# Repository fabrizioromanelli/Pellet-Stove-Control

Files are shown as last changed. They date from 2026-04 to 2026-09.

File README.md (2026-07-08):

# Pellet Stove Control  

<a href="https://buymeacoffee.com/fabrizioroz" target="_blank">
  Buy Me A Coffee
</a>

**I have prebuilt kits, ask me if you need any information!**

This project allows you to smart control any pellet stove controlled via a Micronova Controller N100.
The Arduino project has been compiled for an ESP8266 and successfully tested on a Micronova N100 Controller.
Any other board from Micronova could work, but this is left to the user/developer (probably something changes
on the memory mapping side).
The program is written for Arduino, and it is tested on a D1 Mini with full integration for MQTT (Home Assistant, OpenHAB).

## The Pellet Stove Control works with
the following pellet stoves (please ask me before to check if this could work with your
pellet stove!).
<details>
<summary><b>Compatible pellet stoves</b></summary>

- AMG S.p.A. (Artel, Kalor, Tepor, Foco, Adler)
- Anselmo Cola
- L'Asolana
- Boreal
- Bronpi
- Cadel
- Clam
- Corisit S.r.l. (Lincar, Vulcania, Arce)
- Ecoteck
- EL.FIRE
- EOSS
- EvaCalor
- Fontana Calore
- Fonte Flamme
- Galletti
- Globe-Fire
- Italiana Camini
- Jolly Mec
- Karmek
- Kepo
- Klover
- Laminox
- LMX
- La Nordica S.p.A (Extraflame, Dal Zotto)
- Lorflam
- MCZ (Brisach, Cadel, FreePoint, Pegaso, Red)
- Moretti Design
- Nordic Fire
- Piazetta
- Sicalor
- Solius
- Stufe a pellet Italia
- Tecnoflam
- Termoflam
- Thermoflux
- TS
- Ungaro
- Zibro
- Kalor Compact (boiler, fumesTempAddr 0xFF, flamePowerAddr 0x37)
- ITC Layma (boiler, fumesTempAddr 0x5A, no water pressure value available)
- ETNA Giulia EVO (Micronova J042, fumes temp and power reading doesn't work for the moment)
- Extraflame Teodora Evo (at least turning on works)
- El.Fire Venice Slim
- Palazzetti Ecofire Violetta 7 (tested)
- RED Loto
- MCZ Kaika/Face
- FreePoint Sharp
- Piazetta P958D
- Piazetta Line
- Anselmo Cola Aloe
- Solius Geres
- L'Asolana Marina
</details>

## Components
The following components are needed:
- An ESP8266 (D1 Mini or similar).
- 3 x PC817.
- 3 x 510 Ohms resistors.
- 1 x RJ11 male connector (if your stove has a female RJ11 connected to the serial interface).
- 1 x DB9 (DE-9) male connector (if your stove has an DB9 female connector).

## Circuit diagram
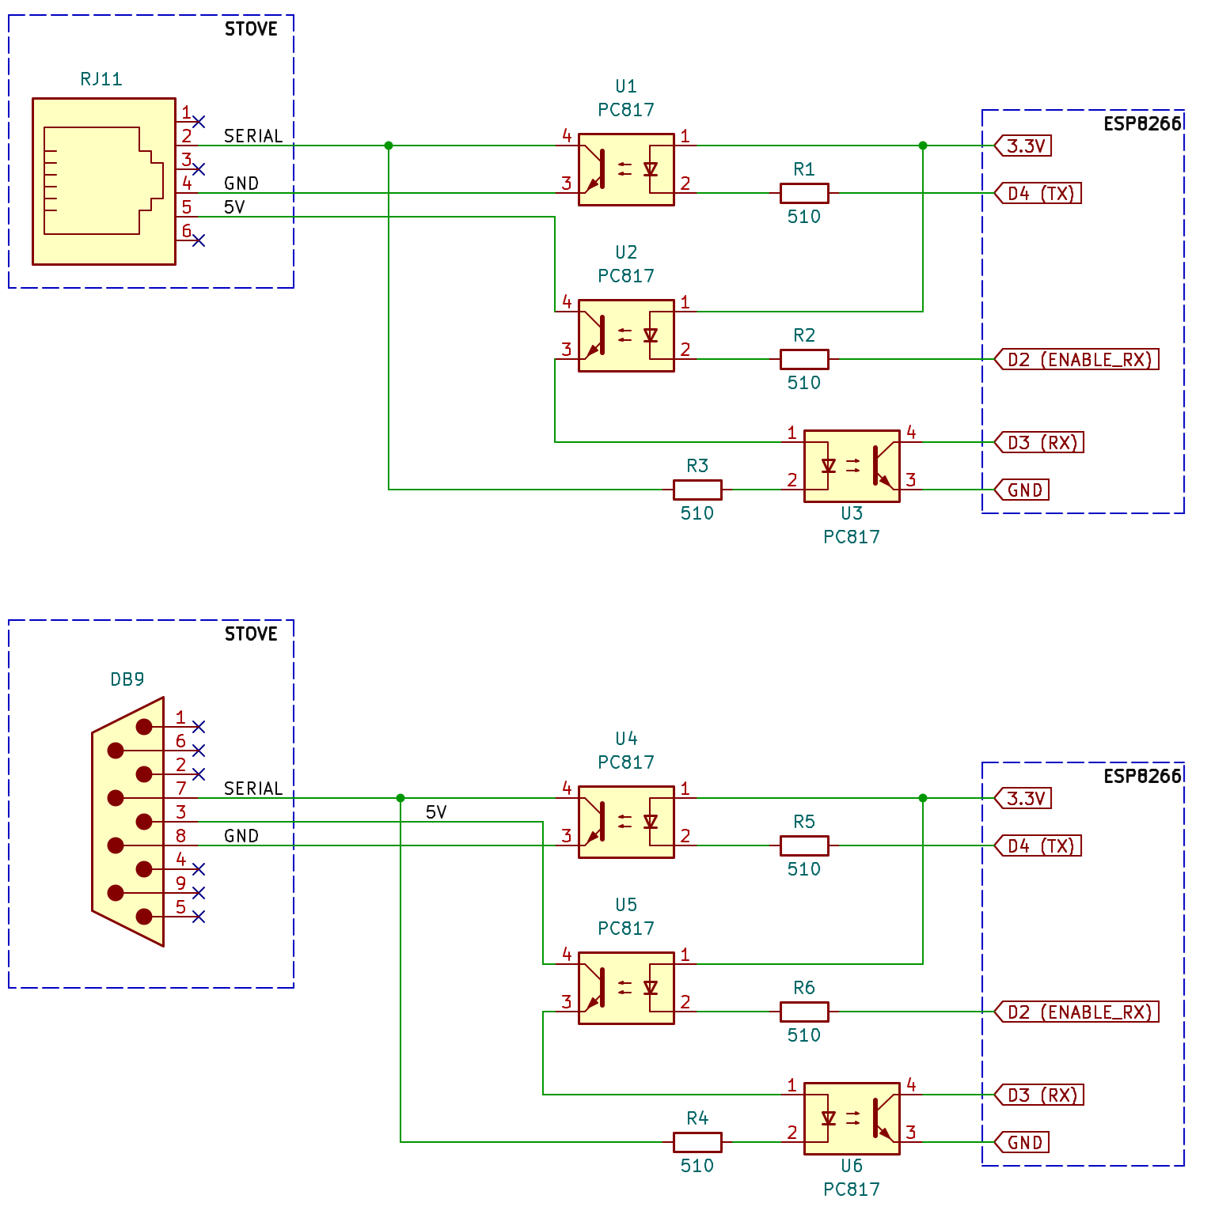
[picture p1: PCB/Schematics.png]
Schematics


For ESP8266 the IN/OUT matrix is:

|ESP8266 I/O|Function|
|---|---|
|`D2`|`Enable RX`|
|`D3`|`RX`|
|`D4`|`TX`|

For ESP32 the IN/OUT matrix is:

|ESP32 I/O|Function|
|---|---|
|`GPIO35`|`Enable RX`|
|`GPIO32`|`RX`|
|`GPIO33`|`TX`|

## Micronova N100 serial port pinout

Serial pinout for both DE-9 and RJ11 connectors

The scheme shows the serial pinout from the Micronova N100 serial port with the connections for both the DE-9 connector and the RJ11 connector.

|Color|Function|
|---|---|
|`Blue`|`Serial`|
|`Red`|`+5V`|
|`Black`|`Ground`|

The fourth pin (the leftmost on the N100 board) is not used.

## PCB project
The folder PCB contains the project for the Printed Circuit Board of the Pellet Stove Control.

Front PCB board:

PCB Front

Back PCB board:

PCB Retro

## Micronova board pinout
For the details related to the board pinout, refer to the manual. This project allows you to interface the stove with the serial port of the Micronova controller. Ask me in case of any doubts.

## Protocol for Micronova controller interface
The protocol for the Micronova controller has been reverse engineered and it is as stable as possible; there is a known problem with writing some values for controlling the stove (such as Flame Power and Fan Speed) that are mapped on the EEPROM (rather than on RAM), however this has been included in the project to let the user control all the stove parameters.

## Building the project
No MQTT parameter needs to be hardcoded in the sketch: everything is configured at first boot through the WiFiManager captive portal and then persisted on the board itself.

- Build the sketch with the Arduino IDE (no editing required)
- Upload the sketch on the board
- On first boot (or whenever the WiFi settings are reset), connect to the `PelletStove-Setup` WiFi network from your phone/PC
- The browser should redirect to the configuration page where you can set up your WiFi credentials, together with the following MQTT parameters:
  - **MQTT server**, the IP or hostname of your MQTT broker
  - **MQTT port**, usually `1883`
  - **MQTT base topic**, the name of the topic you choose to publish on
  - **MQTT user**, if any
  - **MQTT password**, if any
- Once submitted, the board connects to your WiFi/MQTT broker and stores all these settings on the board's flash (LittleFS), so they are restored automatically on every subsequent reboot
- To change the settings later on, reset the WiFi credentials (e.g. via the WiFiManager reset routine) so the `PelletStove-Setup` portal comes up again, pre-filled with the previously saved values

## MQTT topics
- `mqtt_topic`, this is the main topic.
- `connection_state`, this topic contains connection details.
- `state`, this topic contains the detailed status of the stove.
- `power_state`, this topic contains information about the stove power on/off.
- `ta_state`, this topic contains the ambient temperature.
- `ts_state` this topic is used to read the target temperature.
- `tf_state`, this topic is used to read the fumes temperature.
- `p_state`, this topic is used to read the flame power (%).
- `f_state`, this topic is used to read the fan speed (1-5).
- `cmd`, is the topic used to control the stove.

### Command currently supported by the Pellet Stove Control
|Command |Description | Write to |
|---|---|---|
|`ON` |powers on the pellet stove  | RAM |
|`OFF` | shutdown the pellet stove  | RAM |
|`Px`  |sets the power of the pellet stove. e.g. P2 sets the power @ 2 [0 to 5]  | EEPROM |
|`Fx`  |sets the fan speed of the pellet stove. e.g. F0 sets the fan speed to automatic [0 to 5] | EEPROM |
|`Txx`  |sets the target temperature of the pellet stove. e.g. T20 sets the target temperature to 20 °C [10-40]  | EEPROM |
|`E`  |resets any error on the stove | RAM |

Since there is no other way to set flame power/fan speed/temperature rather than writing on the EEPROM, please pay attention to the final integration as EEPROM writes are limited (~10000).

## Home Assistant
For Home Assistant support, please contact me.

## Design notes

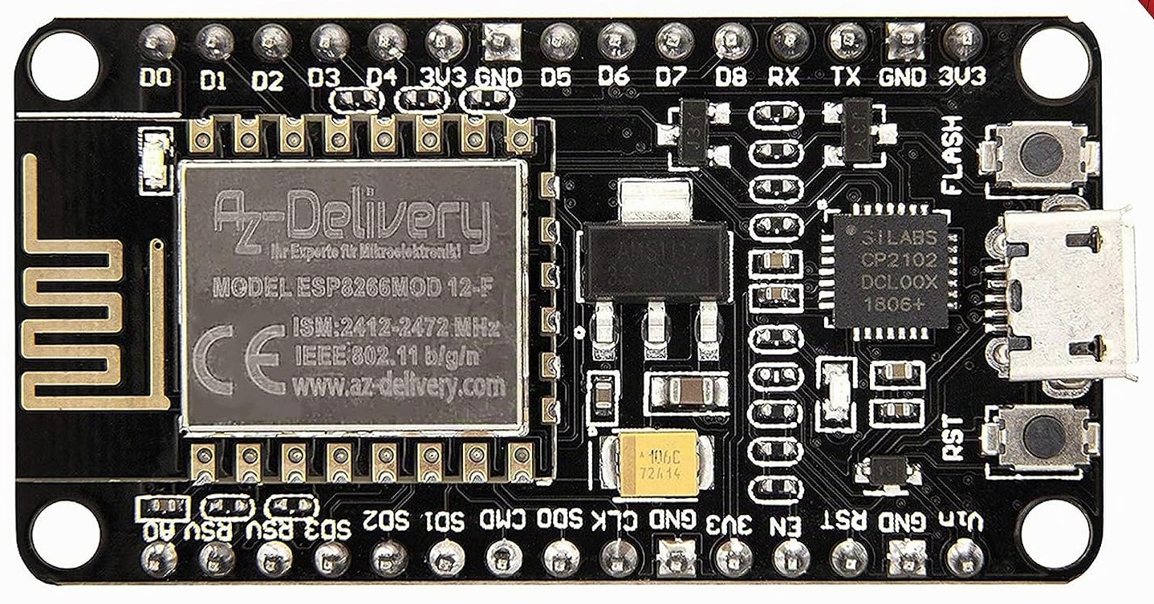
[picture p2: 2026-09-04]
PCB/AZDelivery NodeMCU Amica V2 ESP8266 ESP-12F, Modulo Wifi IoT con CP2102.jpg

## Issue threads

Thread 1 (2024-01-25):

Details for PCB

wes1993, 2024-01-25:
Hello,
thanks a lot for PCB projects, could you give me some information why there are different files?

Best regards
Stefano

fabrizioromanelli, 2024-01-25:
> Hello, thanks a lot for PCB projects, could you give me some information why there are different files?
>
> Best regards Stefano

Sure!
The backup folder inside the PCB folder is just a backup from previous work, you can just ignore it.
All the other files (.kicad*) are used by the KiCAD software to store all the details related to the PCB layers.
Hope this could help! Also, I have some spare PCBs. If you need any, send me an email.

Closed 2024-01-26.

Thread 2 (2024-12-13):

Esphome

goldrake1981, 2024-12-13:
C'è un modo per collegarla a esphome ?
Grazie

fabrizioromanelli, 2024-12-13:
Se esphome supporta MQTT, allora il collegamento è semplice e si può fare.

goldrake1981, 2024-12-13:
Cercavo un modo comodo per installarla su home assistant, soprattutto qualcosa che potesse permettermi di aggiornare il codice con semplicità . Solo che non sono in grado.  Pensavo ci fosse qualche esempio .

fabrizioromanelli, 2024-12-16:
Capisco, prima bisognerebbe installare la parte del firmware su ESP e poi interfacciare la scheda con Home Assistant

goldrake1981, 2024-12-16:
Devo studiare.  Ne so veramente poco e niente.

Closed 2024-12-13.

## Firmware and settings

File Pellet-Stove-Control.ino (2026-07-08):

#include <ArduinoOTA.h>
#include <WiFiManager.h>
#include <PubSubClient.h>
#include <SoftwareSerial.h>
#include <LittleFS.h>

#define AP_NAME "PelletStove-Setup"    // Access point name shown on first boot / config reset
#define CONFIG_FILE "/mqtt_config.txt" // Where MQTT settings are persisted on LittleFS

char mqtt_server[41] = "";
char mqtt_port[7]    = "1883";
char mqtt_topic[41]  = "";
char mqtt_user[21]   = "";
char mqtt_pass[21]   = "";

bool shouldSaveConfig = false; // Set by WiFiManager when the config portal is submitted

unsigned long UPDATE_PERIOD = 1800000; // 30m (in ms)
unsigned long FAST_UPDATE_PERIOD = 60000; // 1m (in ms)

#define FAST_LOOP_CYCLES 30

SoftwareSerial StoveSerial;
#define SERIAL_MODE SWSERIAL_8N2
#define RX_PIN D3
#define TX_PIN D4
#define ENABLE_RX D2

WiFiClient espClient;
PubSubClient client(espClient);
WiFiManager wm;

static volatile bool sem = false;
bool fastUpdate = false;
bool boot = true;
static unsigned long loopCounter = 0;
unsigned long previousMillis = 0;

char connection_topic[52];
char state_topic[52];
char onoff_topic[52];
char ambtemp_topic[52];
char fumetemp_topic[52];
char flame_topic[52];
char fan_topic[52];
char tempset_topic[52];
char cmd_topic[52];

// mqtt_topic is only known at runtime now, so the full topics are built here instead of via macros
void buildTopics() {
  snprintf(connection_topic, sizeof(connection_topic), "%s/connection", mqtt_topic);
  snprintf(state_topic,      sizeof(state_topic),      "%s/state",      mqtt_topic);
  snprintf(onoff_topic,      sizeof(onoff_topic),      "%s/onoff",      mqtt_topic);
  snprintf(ambtemp_topic,    sizeof(ambtemp_topic),    "%s/ambtemp",    mqtt_topic);
  snprintf(fumetemp_topic,   sizeof(fumetemp_topic),   "%s/fumetemp",   mqtt_topic);
  snprintf(flame_topic,      sizeof(flame_topic),      "%s/power",      mqtt_topic);
  snprintf(fan_topic,        sizeof(fan_topic),        "%s/fan",        mqtt_topic);
  snprintf(tempset_topic,    sizeof(tempset_topic),    "%s/tempset",    mqtt_topic);
  snprintf(cmd_topic,        sizeof(cmd_topic),        "%s/cmd",        mqtt_topic);
}

#define device_information "{\"manufacturer\": \"Fabrizio Romanelli\",\"identifiers\": [\"7a396f39-80d2-493b-8e8e-31a70e700bc6\"],\"model\": \"Micronova Controller\",\"name\": \"Micronova Controller\",\"sw_version\": \"1.0.0.0\"}"

#define _RAMR 0x00
#define _RAMW 0x80
#define stoveStateAddr 0x21
#define ambTempAddr 0x01
#define fumesTempAddr 0x3E
#define stovePOnOffAddr 0x58

#define _EEPROMR 0x20
#define _EEPROMW 0xA0
#define powerSetAddr 0x89
#define fanSetAddr 0x8A
#define tempSetAddr 0x8B

// Checksum: Code+Address+Value (hex)
const char stoveOnOff[4] = {_RAMW, stovePOnOffAddr, 0x5A, (char)(_RAMW + stovePOnOffAddr + 0x5A)};
const char stoveOff[4] = {_RAMW, stoveStateAddr, 0x00, (char)(_RAMW + stoveStateAddr + 0x00)};

const char stovePW[6][4] = {
{_EEPROMW, powerSetAddr, 0x00, (char)(_EEPROMW + powerSetAddr + 0x00)},
{_EEPROMW, powerSetAddr, 0x01, (char)(_EEPROMW + powerSetAddr + 0x01)},
{_EEPROMW, powerSetAddr, 0x02, (char)(_EEPROMW + powerSetAddr + 0x02)},
{_EEPROMW, powerSetAddr, 0x03, (char)(_EEPROMW + powerSetAddr + 0x03)},
{_EEPROMW, powerSetAddr, 0x04, (char)(_EEPROMW + powerSetAddr + 0x04)},
{_EEPROMW, powerSetAddr, 0x05, (char)(_EEPROMW + powerSetAddr + 0x05)}
};

const char stoveFN[6][4] = {
{_EEPROMW, fanSetAddr, 0x00, (char)(_EEPROMW + fanSetAddr + 0x00)},
{_EEPROMW, fanSetAddr, 0x01, (char)(_EEPROMW + fanSetAddr + 0x01)},
{_EEPROMW, fanSetAddr, 0x02, (char)(_EEPROMW + fanSetAddr + 0x02)},
{_EEPROMW, fanSetAddr, 0x03, (char)(_EEPROMW + fanSetAddr + 0x03)},
{_EEPROMW, fanSetAddr, 0x04, (char)(_EEPROMW + fanSetAddr + 0x04)},
{_EEPROMW, fanSetAddr, 0x05, (char)(_EEPROMW + fanSetAddr + 0x05)}
};

uint8_t stoveState, tempSet, fumesTemp, flamePower, fanSpeed;
float ambTemp;
char stoveRxData[2];  // When the stove is sending data, it sends two bytes: a checksum and the value

// Utility: non-blocking delay
void nonBlockingDelay(unsigned long ms) {
  unsigned long start = millis();
  while (millis() - start < ms) {
    client.loop();
    ArduinoOTA.handle();
    yield();
  }
}

void setSemaphore(bool value) {
  noInterrupts();
  sem = value;
  interrupts();
}

// Main function to send commands
void sendCommand(const char* _cmd) {
  if (!sem) {
    setSemaphore(true);
  for (int i = 0; i < 4; i++) {
    StoveSerial.write(_cmd[i]);
    nonBlockingDelay(1);
  }
  nonBlockingDelay(50);
  setSemaphore(false);
  }
}

// Loads previously saved MQTT settings from LittleFS, if present
bool loadConfig() {
  if (!LittleFS.begin()) return false;
  if (!LittleFS.exists(CONFIG_FILE)) return false;

  File f = LittleFS.open(CONFIG_FILE, "r");
  if (!f) return false;

  auto readLine = [&](char* buf, size_t len) {
    String s = f.readStringUntil('\n');
    s.trim();
    strncpy(buf, s.c_str(), len - 1);
    buf[len - 1] = '\0';
  };

  readLine(mqtt_server, sizeof(mqtt_server));
  readLine(mqtt_port, sizeof(mqtt_port));
  readLine(mqtt_topic, sizeof(mqtt_topic));
  readLine(mqtt_user, sizeof(mqtt_user));
  readLine(mqtt_pass, sizeof(mqtt_pass));
  f.close();

  return strlen(mqtt_topic) > 0;
}

// Persists the current MQTT settings to LittleFS
void saveConfig() {
  File f = LittleFS.open(CONFIG_FILE, "w");
  if (!f) return;
  f.println(mqtt_server);
  f.println(mqtt_port);
  f.println(mqtt_topic);
  f.println(mqtt_user);
  f.println(mqtt_pass);
  f.close();
}

void saveConfigCallback() {
  shouldSaveConfig = true;
}

void setup_wifi() // Setup WiFiManager, ask for MQTT settings on first boot and connect to WiFi
{
  WiFiManagerParameter custom_mqtt_server("server", "MQTT server", mqtt_server, sizeof(mqtt_server));
  WiFiManagerParameter custom_mqtt_port("port", "MQTT port", mqtt_port, sizeof(mqtt_port));
  WiFiManagerParameter custom_mqtt_topic("topic", "MQTT base topic", mqtt_topic, sizeof(mqtt_topic));
  WiFiManagerParameter custom_mqtt_user("user", "MQTT user", mqtt_user, sizeof(mqtt_user));
  WiFiManagerParameter custom_mqtt_pass("pass", "MQTT password", mqtt_pass, sizeof(mqtt_pass));

  wm.addParameter(&custom_mqtt_server);
  wm.addParameter(&custom_mqtt_port);
  wm.addParameter(&custom_mqtt_topic);
  wm.addParameter(&custom_mqtt_user);
  wm.addParameter(&custom_mqtt_pass);
  wm.setSaveConfigCallback(saveConfigCallback);

  WiFi.mode(WIFI_STA);
  wm.setConnectTimeout(30);
  wm.autoConnect(AP_NAME);

  strncpy(mqtt_server, custom_mqtt_server.getValue(), sizeof(mqtt_server) - 1);
  strncpy(mqtt_port, custom_mqtt_port.getValue(), sizeof(mqtt_port) - 1);
  strncpy(mqtt_topic, custom_mqtt_topic.getValue(), sizeof(mqtt_topic) - 1);
  strncpy(mqtt_user, custom_mqtt_user.getValue(), sizeof(mqtt_user) - 1);
  strncpy(mqtt_pass, custom_mqtt_pass.getValue(), sizeof(mqtt_pass) - 1);

  if (shouldSaveConfig) {
    saveConfig();
    shouldSaveConfig = false;
  }
}

void reconnect() {
  unsigned long startAttemptTime = millis();
  while (!client.connected() && millis() - startAttemptTime < 30000) { // 30 seconds timeout
    Serial.print("Attempting MQTT connection...");
    char clientId[15];
    snprintf(clientId, sizeof(clientId), "ESPClient-%X", random(0xffff));
    if (client.connect(clientId, mqtt_user, mqtt_pass)) {
      client.setBufferSize(1024);
      Serial.println("connected");
      client.subscribe(cmd_topic);
      break;
    } else {
      Serial.print("failed, rc=");
      Serial.println(client.state());
      nonBlockingDelay(5000); // Wait before retrying
    }
  }
}

// This is the callback from a topic arrived via MQTT
void callback(char *topic, byte *payload, unsigned int length) {
  if (length == 0) return;

  if (payload[0] == 'O' && length >= 2) {
    if (payload[1] == 'N') {
      sendCommand(stoveOnOff);
      client.publish(onoff_topic, "ON", true);
    } else if (payload[1] == 'F') {
      sendCommand(stoveOff);
      client.publish(onoff_topic, "OFF", true);
    }
    fastUpdate = true;
  }
  else if (payload[0] == 'P' && length == 2) {
    int idx = payload[1] - '0';
    if (idx >= 0 && idx <= 5) sendCommand(stovePW[idx]);
    fastUpdate = true;
  }
  else if (payload[0] == 'F' && length == 2) {
    int idx = payload[1] - '0';
    if (idx >= 0 && idx <= 5) sendCommand(stoveFN[idx]);
    fastUpdate = true;
  }
  else if (payload[0] == 'T' && length == 3) {
    char t[3] = {(char)payload[1], (char)payload[2], '\0'};
    char tempValue = (char)strtol(t, NULL, 10);
    const char temperatureSet[4] = {_EEPROMW, tempSetAddr, tempValue, (char)(_EEPROMW + tempSetAddr + tempValue)};
    sendCommand(temperatureSet);
    fastUpdate = true;
  }
  else if (payload[0] == 'E') {
    sendCommand(stoveOff);
    client.publish(onoff_topic, "OFF", true);
    fastUpdate = true;
  }
}

void checkStoveReply(unsigned long timeout = 200) {
  unsigned long start = millis();
  uint8_t rxCount = 0;
  stoveRxData[0] = 0x00;
  stoveRxData[1] = 0x00;

  while (millis() - start < timeout) {
    if (StoveSerial.available()) { // It has to be exactly 2 bytes, otherwise it's an error
      stoveRxData[rxCount++] = StoveSerial.read();
      if (rxCount == 2) break;
    }
    yield();
  }
  digitalWrite(ENABLE_RX, HIGH);

  if (rxCount == 2) {
    byte val = stoveRxData[1];
    byte checksum = stoveRxData[0];
    byte param = checksum - val;
    switch (param)
    {
      // RAM Cases
      case stoveStateAddr:
        stoveState = val;
        switch (stoveState)
        {
          case 0:
            client.publish(state_topic, "Spenta", true);
            nonBlockingDelay(1000);
            client.publish(onoff_topic, "OFF", true);
            break;
          case 1:
            client.publish(state_topic, "Avvio", true);
            nonBlockingDelay(1000);
            client.publish(onoff_topic, "ON", true);
            break;
          case 2:
            client.publish(state_topic, "Caricamento pellet", true);
            nonBlockingDelay(1000);
            client.publish(onoff_topic, "ON", true);
            break;
          case 3:
            client.publish(state_topic, "Accensione", true);
            nonBlockingDelay(1000);
            client.publish(onoff_topic, "ON", true);
            break;
          case 4:
            client.publish(state_topic, "Accesa", true);
            nonBlockingDelay(1000);
            client.publish(onoff_topic, "ON", true);
            break;
          case 5:
            client.publish(state_topic, "Pulizia braciere", true);
            break;
          case 6:
            client.publish(state_topic, "Pulizia finale", true);
            nonBlockingDelay(1000);
            client.publish(onoff_topic, "OFF", true);
            break;
          case 7:
            client.publish(state_topic, "Standby", true);
            nonBlockingDelay(1000);
            client.publish(onoff_topic, "OFF", true);
            break;
          case 8:
            client.publish(state_topic, "Pellet mancante", true);
            break;
          case 9:
            client.publish(state_topic, "Mancata accensione", true);
            nonBlockingDelay(1000);
            client.publish(onoff_topic, "OFF", true);
            break;
          case 10:
            client.publish(state_topic, "Allarme", true);
            break;
        }
        break;
      case ambTempAddr:
        ambTemp = (float)val / 2;
        char ambTempStr[10];
        dtostrf(ambTemp, 4, 2, ambTempStr);
        client.publish(ambtemp_topic, ambTempStr, true);
        break;
      case fumesTempAddr:
        fumesTemp = val;
        char fumesTempStr[10];
        sprintf(fumesTempStr, "%d", fumesTemp);
        client.publish(fumetemp_topic, fumesTempStr, true);
        break;
      // EEPROM Cases
      case tempSetAddr + _EEPROMR:
        tempSet = val;
        char tempSetStr[10];
        sprintf(tempSetStr, "%d", tempSet);
        client.publish(tempset_topic, tempSetStr, true);
        break;
      case powerSetAddr + _EEPROMR:
        flamePower = val;
        char flamePowerStr[10];
        sprintf(flamePowerStr, "%d", flamePower);
        client.publish(flame_topic, flamePowerStr, true);
        break;
      case fanSetAddr + _EEPROMR:
        fanSpeed = val;
        char fanSpeedStr[10];
        sprintf(fanSpeedStr, "%d", fanSpeed);
        client.publish(fan_topic, fanSpeedStr, true);
        break;
    }
  }
}

void getStoveState() // Get detailed stove state
{
  const byte readByte = _RAMR;
  StoveSerial.write(readByte);
  nonBlockingDelay(1);
  StoveSerial.write(stoveStateAddr);
  digitalWrite(ENABLE_RX, LOW);
  nonBlockingDelay(80);
  checkStoveReply();
}

void getAmbTemp() // Get room temperature
{
  const byte readByte = _RAMR;
  StoveSerial.write(readByte);
  nonBlockingDelay(1);
  StoveSerial.write(ambTempAddr);
  digitalWrite(ENABLE_RX, LOW);
  nonBlockingDelay(80);
  checkStoveReply();
}

void getFumeTemp() // Get flue gas temperature
{
  const byte readByte = _RAMR;
  StoveSerial.write(readByte);
  nonBlockingDelay(1);
  StoveSerial.write(fumesTempAddr);
  digitalWrite(ENABLE_RX, LOW);
  nonBlockingDelay(80);
  checkStoveReply();
}

void getFlamePower() // Get the flame power
{
  const byte readByte = _EEPROMR;
  StoveSerial.write(readByte);
  nonBlockingDelay(1);
  StoveSerial.write(powerSetAddr);
  digitalWrite(ENABLE_RX, LOW);
  nonBlockingDelay(80);
  checkStoveReply();
}

void getFanSpeed() // Get the fan speed
{
  const byte readByte = _EEPROMR;
  StoveSerial.write(readByte);
  nonBlockingDelay(1);
  StoveSerial.write(fanSetAddr);
  digitalWrite(ENABLE_RX, LOW);
  nonBlockingDelay(80);
  checkStoveReply();
}

void getTempSet() // Get the thermostat setting
{
  const byte readByte = _EEPROMR;
  StoveSerial.write(readByte);
  nonBlockingDelay(1);
  StoveSerial.write(tempSetAddr);
  digitalWrite(ENABLE_RX, LOW);
  nonBlockingDelay(80);
  checkStoveReply();
}

void getStates() // Calls all the get…() functions
{
  getStoveState();
  nonBlockingDelay(100);
  getAmbTemp();
  nonBlockingDelay(100);
  getTempSet();
  nonBlockingDelay(100);
  getFumeTemp();
  nonBlockingDelay(100);
  getFlamePower();
  nonBlockingDelay(100);
  getFanSpeed();
  nonBlockingDelay(100);
  client.publish(connection_topic, "Connected");
}

void setup() {
  digitalWrite(ENABLE_RX, HIGH);
  Serial.begin(115200);
  StoveSerial.begin(1200, SERIAL_MODE, RX_PIN, TX_PIN, false, 256);

  loadConfig();   // Pre-fill defaults from LittleFS, if a config was already saved
  setup_wifi();   // Connects to WiFi; shows the config portal (with MQTT fields) if needed
  buildTopics();  // mqtt_topic is only known now, so build the full topic strings

  ArduinoOTA.setHostname(mqtt_topic[0] ? mqtt_topic : AP_NAME);
  ArduinoOTA.setPassword("micronova");
  ArduinoOTA.begin();

  client.setServer(mqtt_server, atoi(mqtt_port));
  client.setCallback(callback);
  pinMode(ENABLE_RX, OUTPUT);
}

void loop() {
  if (!client.connected()) reconnect();
  client.loop();
  ArduinoOTA.handle();

  unsigned long updatePeriod = fastUpdate ? FAST_UPDATE_PERIOD : UPDATE_PERIOD;
  if ((millis() - previousMillis > updatePeriod) || boot) {
    boot = false;
    previousMillis = millis();
    if (!sem) {
      setSemaphore(true);
      getStates();
      setSemaphore(false);
    }
    client.publish(connection_topic, "Connected");
    if (fastUpdate) loopCounter++;
    if (loopCounter > FAST_LOOP_CYCLES) { fastUpdate = false; loopCounter = 0; }
  }
}

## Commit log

2023-02-25 First commit. Stable version 1.0.0
    [TantrixStoveControl.kicad_pcb, TantrixStoveControl.kicad_sch]
2025-10-23 Update Pellet-Stove-Control.ino removing debug defines and messages
    This version has been tested on the Micronova N100 board.
2026-03-27 Update Pellet-Stove-Control.ino
    Removed reset counter and reset pin (moved changes to feature/reset_D0
    [Pellet-Stove-Control.ino]
2026-04-02 Updating schematics with RJ11 and DB9 connector
2026-04-02 Update README.md
    Updating the schematics for both RJ11 and DB9 connectors
2026-04-02 Updating PCB schemas to KiCad ver. 10.0
    Also adding RJ11 and DB9 connectors schemas.
2026-07-07 Adding excel sheet with detailed stove commands
    Adding excel sheet with detailed pellet stove commands and states for reverse engineering.
    [micronova_stove_commands_mapping.xlsx]
2026-07-07 Adding stove commands and states mapping
    Adding stove commands and states mapping for the Micronova communication protocol
    [micronova_stove_commands_mapping.xlsx]
2026-07-08 Fix typo in nonBlockingDelay call
    [Pellet-Stove-Control.ino]
2026-09-04 Deflating PCB files
    [TantrixStoveControl.kicad_pcb, TantrixStoveControl.kicad_sch]
2026-09-04 New PCB project designed. Check it on KiCad
    [TantrixStoveControl.kicad_pcb]
